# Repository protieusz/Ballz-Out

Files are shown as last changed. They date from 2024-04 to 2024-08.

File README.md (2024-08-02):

# Ballz-Out
Lesovoz style keyboard that fits a Hubris case that has a trackball or trackpad option &amp; EVQ roller encoder. ~~Closed Source.~~ 

Open sourced except my custom designed trackball holder which I spend a lot of time designing it which I will only upload as STL.
I will only upload gerber files since I use EasyEDA to design so converting to pcb file will cause the file to be inaccurate.

Hubris case file you can find in Rain's repo which I don't have the link with right now. No mods on the Hubris case.

Custom switch plate will need to be printed in order to secure the Ballz Out PCB.

No more Group Buys.

Ballz Out is compatible with the following existing cases:

-Campsite

-Campsite+Coriander

-Hubris

-Pomelo

-Carpool

-Barca

-Coriander

~~Currently the PCB is being printed by JLCPCB and will be tested.~~ PCB tested and working after long delay from faulty RP2040 chip. ~~Mini Group/Interest Check will start after Discord channel has been approved in the 40% channel.~~ The channel name is "ballz-out".  I will tweak the switch a little bit to adjust for the EVQ encoder and necessary spacing for the trackball and trackpad. I will have to build another prototype since my only working prototype was sold to my donor. 2nd prototype almost ready. Waiting for the bottom late but everything is working.

To Do:

-Plant to add extra tabs on the switch plate for more case compatibility.

~~-Parse and integrate the working QMK Ieneko42c source code into the Ballz Out. Source files are located in Temp Dump folder for this repo https://github.com/protieusz/Ballz-Out/tree/main/Temp%20Dump.~~
Trackpad code is borrowed from Darakuneko and the only modification I did for the QMK is to replace his matrix layout with mine. The rest are the same.

As for the trackball QMK code, I borrowed from aki27's code and the same thing, matrix was modded and some VIAL statements was removed or else it will not compliled. No real support for QMK will be giving. It is best to ask the QMK discord channel for any specifics to QMK coding.

Working Prototype:
























Wire Bodgle For Fault GPIO Pin For A Column:


Photo on 2024-03-22 at 4 39 PM















Keycaps Test Fit:


Fusion360 Render:
PMW3360 Trackball 25mm or 34mm Option (Rev 1):
Screenshot_2024-02-10_at_8 09 13_PM

Azoteq 65mm Trackpad Option (Will update holes in the pcb for Rev 2):
Screenshot 2024-02-16 at 2 21 30 PM
Screenshot 2024-02-16 at 2 26 19 PM
Screenshot 2024-02-16 at 2 48 38 PM

Azoteq 43mm Trackpad Option (Rev 1):
Screenshot 2024-02-15 at 4 02 42 PM
Screenshot_2024-02-11_at_9 34 55_AM
Screenshot_2024-02-09_at_5 31 40_PM
Finalized Switch Plate
Screenshot_2024-02-13_at_12 13 51_PM

Screenshot 2024-02-12 at 2 20 39 PM
Screenshot 2024-02-12 at 2 20 53 PM
Screenshot 2024-02-12 at 2 21 07 PM
Screenshot 2024-02-12 at 2 21 23 PM
Screenshot 2024-02-12 at 2 21 48 PM
Screenshot 2024-02-12 at 2 22 00 PM

# License

MIT licensed.

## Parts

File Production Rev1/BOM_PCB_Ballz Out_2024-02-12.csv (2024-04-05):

ID | Name | Designator | Footprint | Quantity | Manufacturer Part | Manufacturer | Supplier | Supplier Part | Price | link
1 | 1uF | C1,C2,C5,C6,C9 | C0402 | 5 | CL05A105KA5NQNC | SAMSUNG(三星) | LCSC | C52923 | 0.004 | https://item.szlcsc.com/15869.html
2 | SM4007PL | D304,D008,D308,D100,D101,D102,D103,D104,D200,D201,D202,D203,D204,D301,D302,D303,D305,D300,D311,D000,D001,D002,D003,D004,D007,D009,D010,D011,D107,D108,D109,D110,D111,D207,D208,D209,D210,D211,D307,D309,D310,D306 | SOD-123F_L2.8-W1.8-LS3.7-RD | 42 | SM4007PL | MDD | LCSC | C64898 | 0.007 | https://item.szlcsc.com/60254.html
3 | PRTR5V0U2X,215 | D11 | SOT-143_L2.9-W1.3-P1.92-LS2.3-BR | 1 | PRTR5V0U2X,215 | Nexperia(安世) | LCSC | C12333 | 0.148 | https://item.szlcsc.com/280548.html
4 | BSMD0805-020-15V | F1 | F0805 | 1 | BSMD0805-020-15V | BHFUSE(佰宏) | LCSC | C883103 | 0.045 | https://item.szlcsc.com/343298.html
5 | FH34SRJ-6S-0.5SH(50) | FPC2-HIROSE6PINS | FFC-SMD_6P-P0.50_FH34SRJ-6S-0.5SH | 1 | FH34SRJ-6S-0.5SH(50) | HRS(广濑) | LCSC | C224194 | 0.09 | https://item.szlcsc.com/224431.html
6 | 5.1kΩ | R1,R2,R3,R4,R5 | R0402 | 5 | 0402WGF5101TCE | UNI-ROYAL(厚声) | LCSC | C25905 | 0.001 | https://item.szlcsc.com/323315.html
7 | W25Q128JVSIQTR | U3 | SOIC-8_L5.3-W5.3-P1.27-LS8.0-BL | 1 | W25Q128JVSIQ | WINBOND(华邦) | LCSC | C97521 | 0.652 | https://item.szlcsc.com/63461.html
8 | RP2040 | U4 | LQFN-56_L7.0-W7.0-P0.4-EP | 1 | RP2040 | Raspberry Pi(树莓派) | LCSC | C2040 | 1.076 | https://atta.szlcsc.com/upload/public/pdf/source/20210621/C2040_96F425825606B7957D87DD32E2512CA9.pdf
9 | XC6206P332MR | U5 | SOT-23-3_L2.9-W1.6-P1.90-LS2.8-BR | 1 | XC6206P332MR | TOREX(特瑞仕) | LCSC | C5446 | 0.104 | https://item.szlcsc.com/14454.html
10 | SN74LVC1T45QDCKRQ1 | U6 | SC-70-6_L2.0-W1.3-P0.65-LS2.1-BR | 1 | SN74LVC1T45QDCKRQ1 | TI(德州仪器) | LCSC | C139353 | 0.525 | https://lcsc.com/eda_search?q=C139353&%26type=1&ref=editor
11 | PMW3360DM-T2QU | U7 | PMW3360DM-T2QU.PACK | 1 | PMW3360DM-T2QU |  |  |  |  | http://www.pixart.com/upload/PMS0058-PMW3360DM-T2QU-NNDS-R1.30-06042016_20160902201411.pdf
12 | AP2127K-ADJTRG1 | U8 | SOT-23-5_L3.0-W1.7-P0.95-LS2.8-BR | 1 | AP2127K-ADJTRG1 | DIODES(美台) | LCSC | C96343 | 0.059 | https://lcsc.com/eda_search?q=C96343&%26type=1&ref=editor
13 | TYPE-C-31-M-12 | USBC1 | USB-C_SMD-TYPE-C-31-M-12 | 1 | TYPE-C-31-M-12 | 韩国韩荣 | LCSC | C165948 | 0.167 | https://so.szlcsc.com/global.html?c=&k=C165948
14 | 12MHz | X1 | OSC-SMD_4P-L3.2-W2.5-BL | 1 | X322512MSB4SI | YXC(扬兴晶振) | LCSC | C9002 | 0.062 | https://item.szlcsc.com/15866.html
15 | 22pF | C3,C4 | C0402 | 2 | 0402CG220J500NT | FH(风华) | LCSC | C1555 | 0.001 | https://item.szlcsc.com/15869.html
16 | 100nF | C7,C10,C11,C12,C13,C14,C15,C16 | C0402 | 8 | CL05B104KO5NNNC | SAMSUNG(三星) | LCSC | C1525 | 0.001 | https://item.szlcsc.com/15869.html
17 | 10uF | C8 | C0402 | 1 | CL05A106MQ5NUNC | SAMSUNG(三星) | LCSC | C15525 | 0.005 | https://item.szlcsc.com/15869.html
18 | 4.7uF | C17,C19,C20 | C0402 | 3 | CL05A475MP5NRNC | SAMSUNG(三星) | LCSC | C23733 | 0.006 | https://lcsc.com/eda_search?q=C23733&%26type=1&ref=editor
19 | 100nF | C18 | C0402 | 1 | CL05B104KB54PNC | SAMSUNG(三星) | LCSC | C307331 | 0.006 | https://lcsc.com/eda_search?q=C307331&%26type=1&ref=editor
20 | 1kΩ | R6,R7 | R0402 | 2 | 0402WGF1001TCE | UNI-ROYAL(厚声) | LCSC | C11702 | 0.001 | https://item.szlcsc.com/323315.html
21 | 27Ω | R8,R9 | R0402 | 2 | 0402WGF270JTCE | UNI-ROYAL(厚声) | LCSC | C25100 | 0.001 | https://item.szlcsc.com/323315.html
22 | 10kΩ | R10,R12,R13 | R0402 | 3 | 0402WGF1002TCE | UNI-ROYAL(厚声) | LCSC | C25744 | 0.001 | https://lcsc.com/eda_search?q=C25744&%26type=1&ref=editor
23 | 39Ω | R11 | R0402 | 1 | 0402WGJ0390TCE | UNI-ROYAL(厚声) | LCSC | C25164 |  | https://lcsc.com/eda_search?q=C25164&%26type=1&ref=editor
24 | 15kΩ | R14 | R0402 | 1 | 0402WGF1502TCE | UNI-ROYAL(厚声) | LCSC | C25756 | 0.001 | https://lcsc.com/eda_search?q=C25756&%26type=1&ref=editor
25 | RESET | U1 | RESET SWITCH | 1
26 | BOOT | U2 | RESET SWITCH | 1
27 | SK6812MINI-E_C5149201 | U13,U14,U15,U16 | LED-SMD_L3.2-W2.8-TR | 4 | SK6812MINI-E | 欧思科光电 | LCSC | C5149201 | 0.163 | https://lcsc.com/eda_search?q=C5149201&%26type=1&ref=editor
28 | Switch | K308,KK307,K100,K101,K102,K103,K104,K200,K201,K202,K203,K204,K301,K302,K303,K304,K305,K300,K311,K000,K001,K002,K003,K004,K007,K008,K009,K010,K011,K107,K108,K109,K110,K111,K207,K208,K209,K210,K211,K309,K310,K306 | CHERRY_MX_100_MILLMAX | 42
29 | MX_ALPS-2U-REVERSEDSTABILIZERS-NOLED | KK304,K307 | MX_ALPS-2U-REVERSEDSTABILIZERS-NOLED | 2
30 | Roll Encoder - EVQWGD001 | U304 | EVQWGD001 ENCODER | 1 | EVQWGD001 | Panasonic | Aliexpress | EVQWGD001

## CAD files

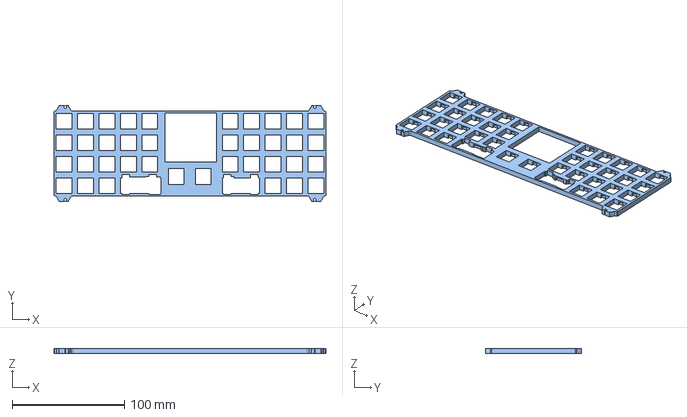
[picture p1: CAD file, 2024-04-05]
Ballz Out 4.5mm thick EVQ Notches.step
241.8 x 85.1 x 4.50 mm

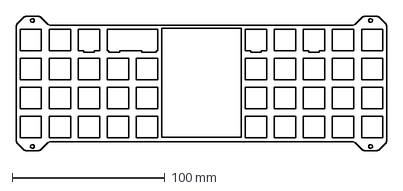
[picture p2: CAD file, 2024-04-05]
Production Rev1/Switch Plate/Lesovoz_Connected_Coriander.dxf
242.9 x 88.2 mm

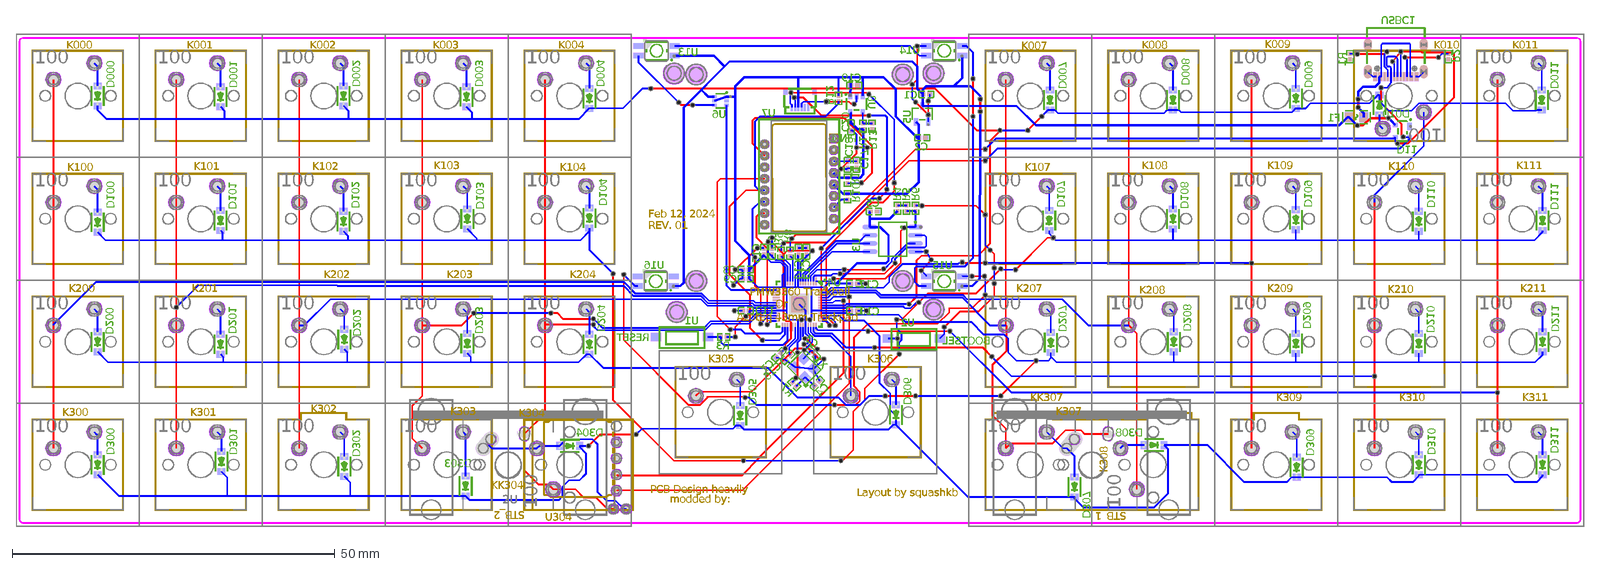
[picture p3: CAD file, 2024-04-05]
Production Rev1/Switch Plate/PCB_Ballz Out_2024-02-13.dxf
Feb 12, 2024
REV. 01
Layout by squashkb
PCB Design heavily
modded by:
PMW3360 Trackball
Or
Azoteq 43mm Trackpad
PIN 1
RESET
BOOTSEL
STB_2
STB_1
K308
100
KK307
KK304
2U
K100
K101
K102
K103
K104
K200
K201
K202
K203
K204
K301
K302
K303
K304
K305
K300
K311
K000
K001
K002
K003
K004
K007
K008
K009
K010
K011
K107
K108
K109
K110
K111
K207
K208
K209
K210
K211
K307
K309
K310
U304
K306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

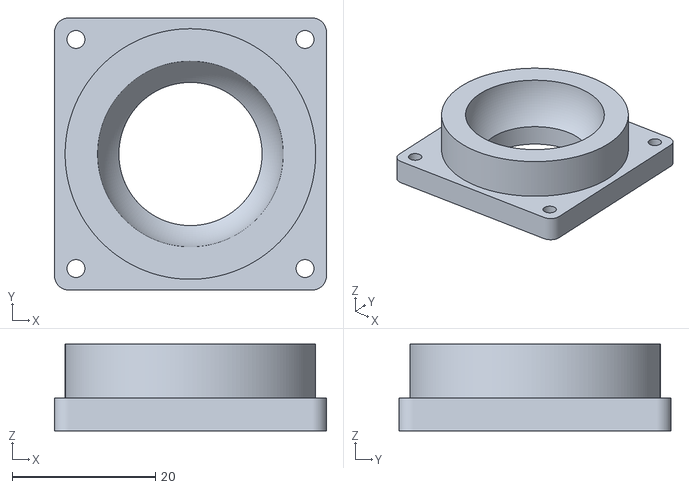
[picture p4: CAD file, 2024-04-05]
Trackball 26mm.stl
38.0 x 38.0 x 12.1

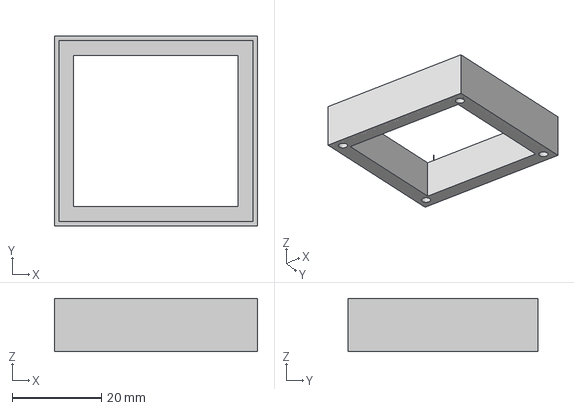
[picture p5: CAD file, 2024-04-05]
Azoteq43mm stand.step
45.6 x 42.6 x 12.0 mm

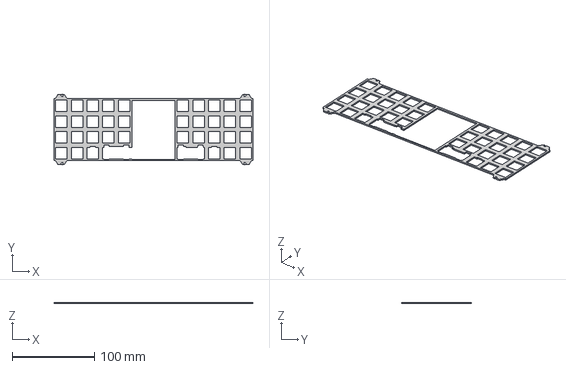
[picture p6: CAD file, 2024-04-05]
Production Rev1/Switch Plate/Legend v44.step
241.8 x 85.1 x 1.50 mm

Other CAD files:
Production Rev1/Switch Plate/Lesovoz Corrected Plate.stl

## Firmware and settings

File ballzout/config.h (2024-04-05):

// Copyright 2024 ProtieusKeebs
// SPDX-License-Identifier: GPL-2.0-or-later

#pragma once

//#define VIAL_KEYBOARD_UID {0xC4, 0x18, 0xCC, 0x6D, 0x1C, 0x16, 0x5B, 0x8D}
//#define VIAL_UNLOCK_COMBO_ROWS {0, 0}
//#define VIAL_UNLOCK_COMBO_COLS {1, 11}

/* VIA */
//#define DYNAMIC_KEYMAP_LAYER_COUNT 8


/* key matrix size */
//#define MATRIX_COLS 13
//#define MATRIX_ROWS 4


/* tapping term */
// #define TAPPING_FORCE_HOLD
//#define TAPPING_TERM 200
// #define IGNORE_MOD_TAP_INTERRUPT

#define RP2040_BOOTLOADER_DOUBLE_TAP_RESET // Activates the double-tap behavior
#define RP2040_BOOTLOADER_DOUBLE_TAP_RESET_TIMEOUT 200U // Timeout window in ms in which the double tap can occur.

#ifdef COMBO_ENABLE
#    define COMBO_COUNT 2
#    define COMBO_TERM 200
#endif

/* Encoder */
//#define ENCODERS_PAD_A { GP11 }
//#define ENCODERS_PAD_B { GP12 }
//#define ENCODER_RESOLUTION 4

/* Matrix*/
//#define MATRIX_COL_PINS { GP25, GP24, GP23, GP22, GP21, GP26, GP27, GP20, GP19, GP18, GP17, GP16, GP13 }
//#define MATRIX_ROW_PINS { GP28, GP10, GP14, GP15 }

/* COL2ROW, ROW2COL */
//#define DIODE_DIRECTION COL2ROW


/* Set 0 if debouncing isn't needed */
//#define DEBOUNCE 5


/* Mechanical locking support. Use KC_LCAP, KC_LNUM or KC_LSCR instead in keymap (Very Important for Scroll Lock!!!) */
#undef LOCKING_SUPPORT_ENABLE
/* Locking resynchronize hack */
#undef LOCKING_RESYNC_ENABLE


/* RGB LED */
//#define WS2812_PIO_USE_PIO1
#define WS2812_DI_PIN GP29

#ifdef RGBLIGHT_ENABLE
    #define RGBLIGHT_LED_COUNT 4
    //#define RGBLED_NUM 4
    #define RGBLIGHT_LIMIT_VAL 80
    #define RGBLIGHT_HUE_STEP 10
    #define RGBLIGHT_SAT_STEP 17
    #define RGBLIGHT_VAL_STEP 17

    //#define RGBLIGHT_ANIMATIONS
    #define RGBLIGHT_EFFECT_BREATHING
    #define RGBLIGHT_EFFECT_RAINBOW_MOOD
    #define RGBLIGHT_EFFECT_RAINBOW_SWIRL
    #define RGBLIGHT_EFFECT_SNAKE
    #define RGBLIGHT_EFFECT_KNIGHT
    #define RGBLIGHT_EFFECT_CHRISTMAS
    #define RGBLIGHT_EFFECT_STATIC_GRADIENT
    #define RGBLIGHT_EFFECT_TWINKLE
    #define RGBLIGHT_EFFECT_ALTERNATING
#endif


/* Trackball */

#ifdef POINTING_DEVICE_ENABLE

//#    undef RP_SPI_USE_SPI0
//#    define RP_SPI_USE_SPI0 TRUE
//#    undef RP_SPI_USE_SPI1
//#    define RP_SPI_USE_SPI1 FALSE
#    define SPI_DRIVER SPID0

//#    define SPI_SCK_PIN GP22 //6
//#    define SPI_MISO_PIN GP24 //4
//#    define SPI_MOSI_PIN GP23 //7
#    define SPI_SCK_PIN GP18
#    define SPI_MISO_PIN GP16
#    define SPI_MOSI_PIN GP19

#endif


#ifndef PMW33XX_CS_PIN
#    define PMW33XX_CS_PIN GP17
#endif
#define POINTING_DEVICE_INVERT_X
#define POINTING_DEVICE_INVERT_Y
//#define ROTATIONAL_TRANSFORM_ANGLE 90
#define POINTING_DEVICE_ROTATION_180

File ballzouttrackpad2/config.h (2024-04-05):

// Copyright 2024 ProtieusKeebs
// SPDX-License-Identifier: GPL-2.0-or-later

#pragma once

#define RP2040_BOOTLOADER_DOUBLE_TAP_RESET // Activates the double-tap behavior
#define RP2040_BOOTLOADER_DOUBLE_TAP_RESET_TIMEOUT 200U // Timeout window in ms in which the double tap can occur.

/*******************************************/
/***** Trackpad code by Daraku-Neko start *****/
/*******************************************/

#ifdef COMBO_ENABLE
#    define COMBO_COUNT 2
#    define COMBO_TERM 200
#endif

#define RGB_MATRIX_KEYPRESSES
#define RGB_MATRIX_FRAMEBUFFER_EFFECTS
#define RGB_MATRIX_DEFAULT_MODE RGB_MATRIX_CYCLE_UP_DOWN

#define I2C1_SDA_PIN        GP10
#define I2C1_SCL_PIN        GP11

/* Haptic feedback */
#define DRV2605L_FB_ERM_LRA 0
#define DRV2605L_FB_BRAKEFACTOR 3 // For 1x:0, 2x:1, 3x:2, 4x:3, 6x:4, 8x:5, 16x:6, Disable Braking:7
#define DRV2605L_FB_LOOPGAIN 1 // For  Low:0, Medium:1, High:2, Very High:3
/* Motor settings */
#define DRV2605L_RATED_VOLTAGE 3
#define DRV2605L_V_PEAK 5
#define DRV2605L_V_RMS 2.0
#define DRV2605L_F_LRA 205 /* resonance freq */

#define DRV2605L_DEFAULT_MODE 0
#define DRV2605L_GREETING  DRV2605L_EFFECT_750_MS_ALERT_100

#define EECONFIG_USER_DATA_SIZE 6

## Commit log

2024-03-08 QMK Source
    Not working yet.
    [config.h, keymap.c]
2024-04-05 Production Files
    [Azoteq43mm stand.step, BOM_PCB_Ballz Out_2024-02-12.csv, Ballz Out 4.5mm thick EVQ Notches.step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]
